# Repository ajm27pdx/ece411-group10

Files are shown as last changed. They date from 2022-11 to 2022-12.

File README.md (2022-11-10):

# ECE411 Group 10 - 2022 Fall Practicum Project

## Members
* Jing Ma
* Adam Martinez
* Janvier Mpfizi
* Tysen Tippetts
## Product Design Specifications
[>>HERE<<](PDS/PDS.md)
## Funcitonal Decomposition
### L0
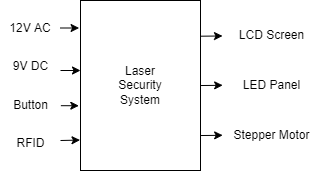
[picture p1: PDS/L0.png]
L0

### L1
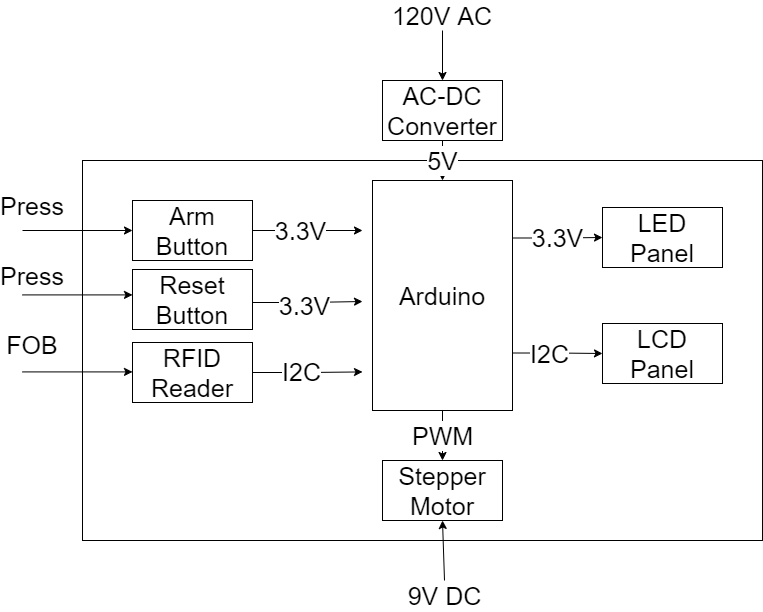
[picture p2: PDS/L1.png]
L1

## Bill of Materials
[Google Sheets Link](https://docs.google.com/spreadsheets/d/1Y6daa6rxvxdisMLShwMxon2ES7SXVknLk-44MzFfnI0/edit?usp=sharing)
### Controllers
- Arduino Uno
### Sensors
- Photoresistors
- RFID Sensor RC522
- Button
### Actuators
- Servo Motor SG90
- LED Lasor 6mm 5mW Red Dot Laser
- LCD Screen 1602 w/ I2C controller
### Misc
- Wires
- RFID Fob
- Resistors
- 3D Printed Enclosure

## Software
- [KiCAD](https://www.kicad.org/) -- Schematic and PCB Layout
- [FreeCAD](https://www.freecadweb.org/) -- 3D Modeling
- [ProjectLibre](https://www.projectlibre.com/) -- Project Management

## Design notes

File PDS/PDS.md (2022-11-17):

# Group 10 - Product Design Specification

## Executive Summary / Concept of Operations
Our product is an anti-theft device that will send out an alert whenever a laser beam across the defensible area is broken. This idea came from spy movies, and we thought that would be useful if we use it to prevent theft from happening. We think most house owners in the world could use it in the room where they keep their valuable things, and some banks, museums, or places that kept confidential information may also be interested in it if the device has enough laser beam to cover the room. Before we are using it, we will need to install the same number of pairs of laser pointers and photoresistors on both sides of the walls, each laser pointer must be precisely aimed at the corresponding photoresistors. There will be a controller that has a series of buttons to arm and reset the device, so it could be turned on and turned off when the buzzer or LED for an alarm on the device is on.
## Brief Market Analysis
Our intended customers are anybody that might have a need to protect a space through the use of a neat, futuristic method. The scale of the product can be altered to protect a hallway or a small enclosure for something important. Our primary competition is other, more mundane security systems such as those that use magnets to secure doors or sonic sensors to secure spaces. As the scale can change based on the needs of the customer, this could lead to a consultation service that can develop and customize the product to each individual’s needs. The components are not particularly expensive, but this service could drive some of the cost.
## Requirements
-   Must have arm/disarm interactions
-   Must detect when the laser beam is broken to the photoresistor
-   Must alert when beam is broken and the alarm is armed, this can be audio and/or visual
-   Must use RFID Fob authorization for disarming
-   Should have a test jig in order to be portable for display
## System Architecture

## Design Specification
### Sensors
- Buttons to arm and disarm, depending on time and desired complexity this can be expanded to a PIN pad or even fingerprint sensor
- Photoresistors to detect the beam and calibrate using ambient light
### Actuators
- An alarm system, can consist of audio buzzers and/or LEDs  
- Servo motor to arm the laser, this is an optional addition
### Processors
- Arduino will be used to the control system
- The Arduino IDE will be able to handle the logic that we’ll need
### Power
- A COTS 5V wall plug will power the Arduino, the stepper motor will have it's own 9V battery power supply through a COTS buck converter.

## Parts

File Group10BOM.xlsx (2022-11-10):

Bill Of Materials for: Team 10 [TEAM NAME]
Last modified: [10/11/2022]
PCB version: [PCB VERSION #]
BOM revision: [BOM REVISION #] |  | P/NP | = Place/Not Place (components marked NP are not stuffed on the board)
Cnt | Part References | P/NP | Mfg | Mfg PN | Description | Dist | Dist Part Number | Cost Ea. | Cost Total
5 | IS1,IS2,IS3, IS4, IS5 | P | IS | 276810 | 1µF ±10% 16V Ceramic Capacitor X5R 0603 | Digi-Key | KY-008 5mW | $0.50 | $2.50
2 | R1,R2 | p | Vishay Dale | CMF5550R000FKEK70 | RES 50 OHM 1/2W 1% AXIAL | Digi-Key | RES 50 OHM 1/2W 1% AXIAL | $0.63 | $1.26
1 | LCD | P | Adafruit Industries LLC | 1528-1505-ND | LCD MODULE 32 DIG 16 X 2 R/G/B | Digikey | 541-4226-ND | $12.00 | $12.00
1 | IDE | p | Arduino | 1050-1024-ND | Arduino Uno R3 | Dig Key | ARDUINO UNO R3 ATMEGA328P EVAL | $27.00 | $27.00
1 | DC Motor | p | Hitec Commercial Solutions | 2589-31311S-ND | HS-311 STANDARD ECONOMY | DigiKey | 31311S | $13.49 | $13.49
1 | Chip | p | NXP USA Inc. | 568-2206-5-ND | IC RFID READER 125KHZ 14SO | GigKey | HTRC11001T/02EE,11 | $4.49 | $4.49
1 | PhotoResistor | p | NTE Electronics, Inc | 2368-02-LDR4-ND | 5MM LDR 30K-50K OHM | DigiKey | 02-LDR4 | $0.23 | $0.23
1 | RfID | NP | MikroElektronika | 1471-1165-ND | RFID READER READ ONLY 125KHZ MOD | DigKey | MIKROE-262 | $24.00 | $24.00
 |  |  |  |  |  |  | TOTAL: | $84.97

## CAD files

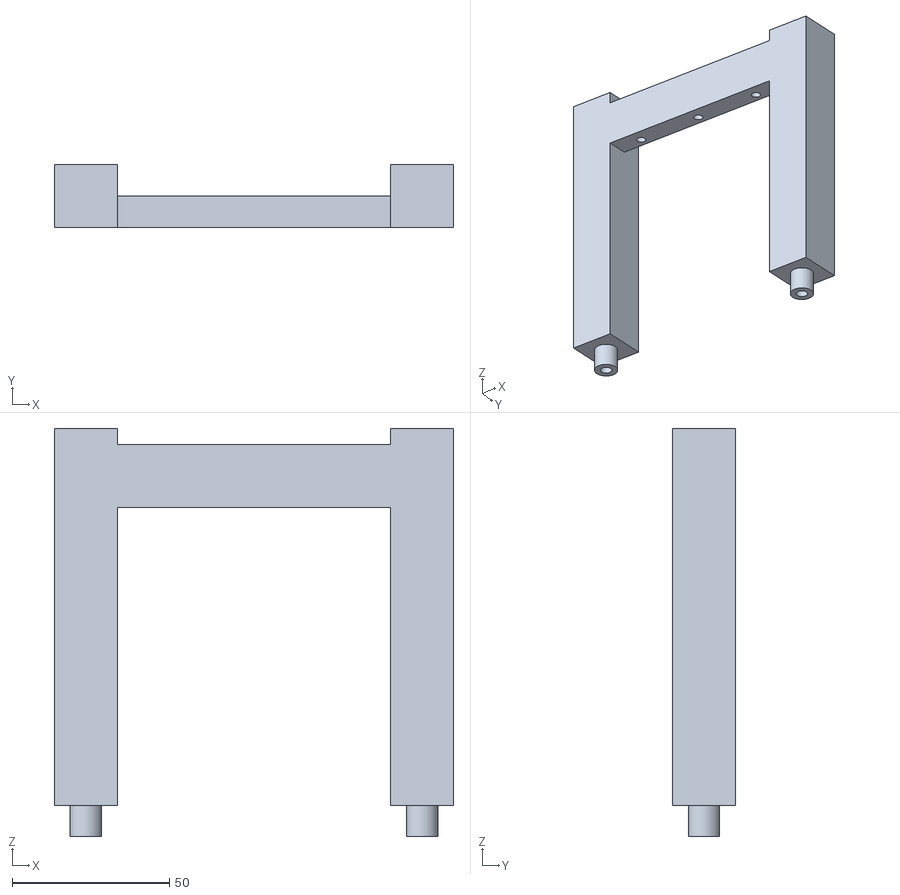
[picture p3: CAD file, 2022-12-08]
CAD/stlFiles/gantryv2.stl
127.0 x 20.0 x 130.0

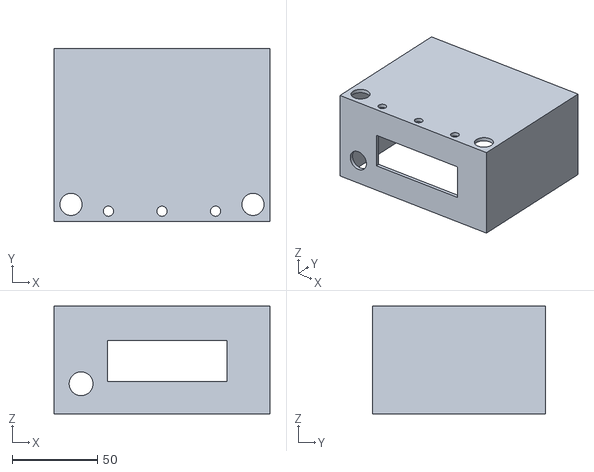
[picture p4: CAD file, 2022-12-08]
CAD/stlFiles/shellv3.stl
127.0 x 101.6 x 63.5

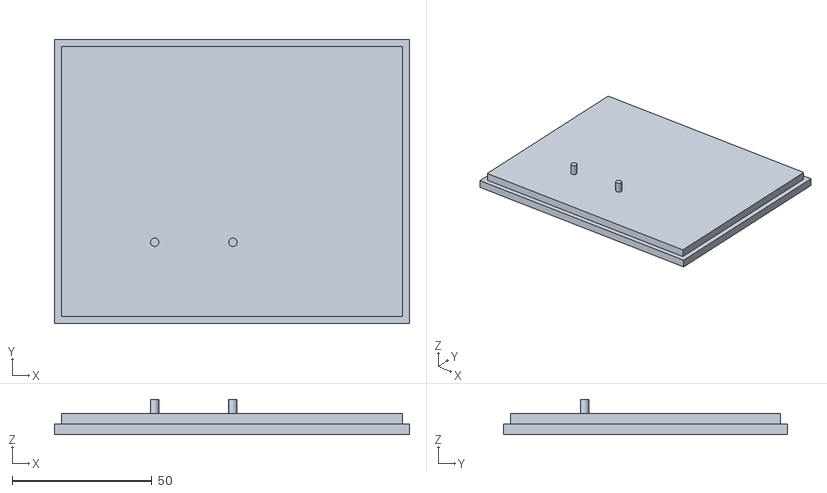
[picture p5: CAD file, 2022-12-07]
CAD/stlFiles/basev1.stl
127.0 x 101.6 x 12.6

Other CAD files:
CAD/stlFiles/shellv2.stl
CAD/stlFiles/gantryv1.stl

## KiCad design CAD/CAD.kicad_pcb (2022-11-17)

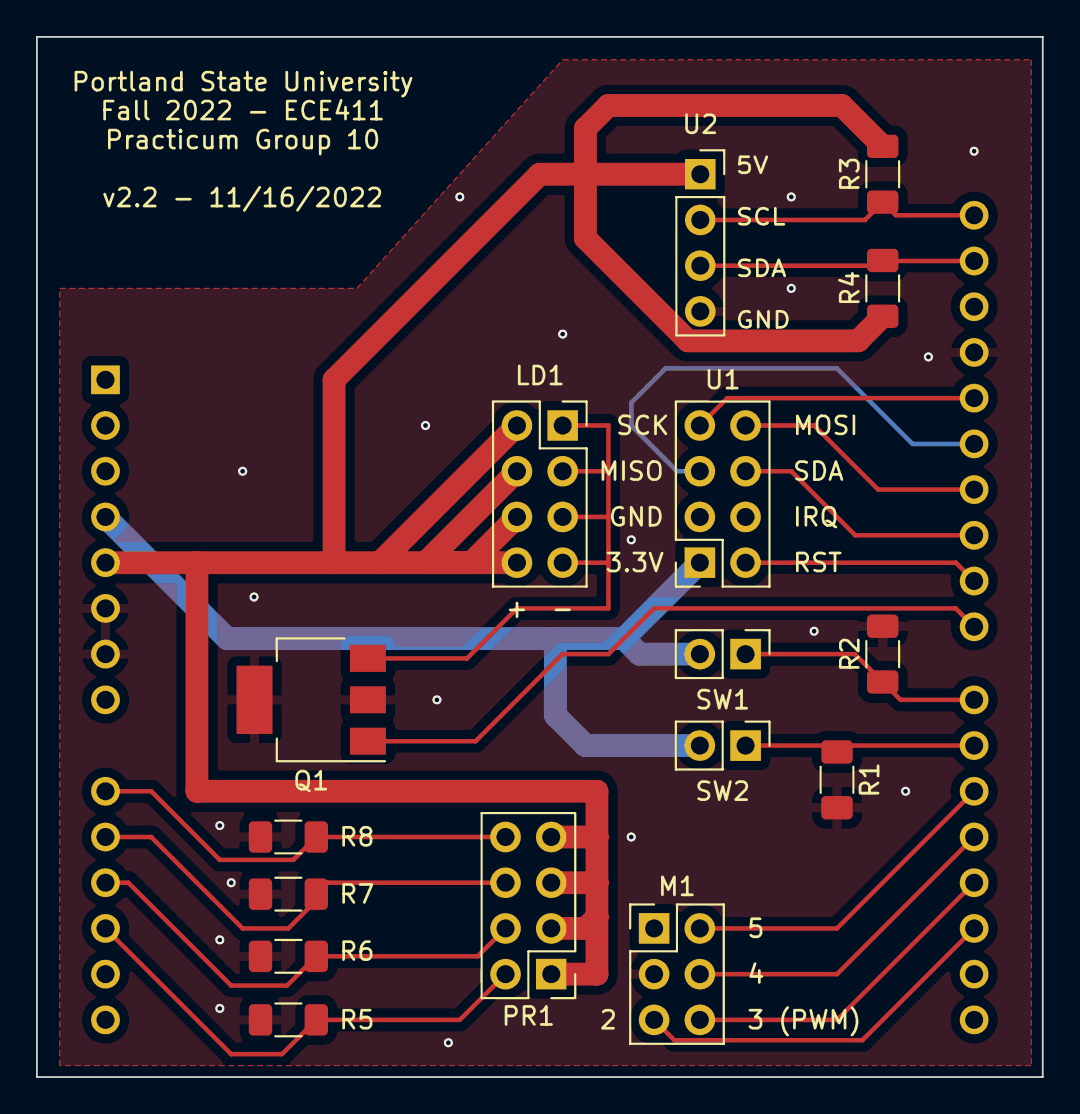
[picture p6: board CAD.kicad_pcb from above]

Board: 2 copper layers, 55.9 x 57.8 mm, 17 parts (1 on the bottom side), 22 nets.

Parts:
A1: Arduino_UNO_R3
LD1: D_Laser_1C2A; PinSocket_2x04_P2.54mm_Vertical
M1: Motor_Servo_Hitec; PinHeader_2x03_P2.54mm_Vertical
PR1: R_Photo; PinHeader_2x04_P2.54mm_Vertical
Q1: 2N7002; SOT-223-3_TabPin2
R1, R2, R5, R6, R7, R8: 10k; R_1206_3216Metric_Pad1.30x1.75mm_HandSolder
R3, R4: 4.7k; R_1206_3216Metric_Pad1.30x1.75mm_HandSolder
SW1, SW2: SW_Push; PinHeader_1x02_P2.54mm_Vertical
U1: RFID_RC522; PinSocket_2x04_P2.54mm_Vertical
U2: LCD_1602_I2C; PinSocket_1x04_P2.54mm_Vertical

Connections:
+3.3V: A1.4 (3V3), SW1.2, SW2.2, U1.1 (3.3V)
+5V: A1.5 (+5V), LD1.2 (A), LD1.4, LD1.6, LD1.8, PR1.1, PR1.3, PR1.5, PR1.7, R3.2, R4.1, U2.1 (VCC)
GND: A1.6 (GND), A1.7 (GND), A1.29 (GND), M1.3 (-), Q1.2 (S), R1.2, R2.2, R5.2, R6.2, R7.2, R8.2, U2.4 (GND)
unnamed: A1.9 (A0), PR1.8, R8.1
unnamed: A1.10 (A1), PR1.6, R7.1
unnamed: A1.11 (A2), PR1.4, R6.1
unnamed: A1.12 (A3), PR1.2, R5.1
unnamed: A1.17 (D2), M1.5
unnamed: A1.18 (D3), M1.6
unnamed: A1.19 (D4), M1.4
unnamed: A1.20 (D5), M1.2 (PWM)
unnamed: A1.21 (D6), R1.1, SW2.1
unnamed: A1.22 (D7), R2.1, SW1.1
unnamed: A1.23 (D8), Q1.1 (G)
unnamed: A1.24 (D9), U1.2 (RST)
unnamed: A1.25 (D10), U1.6 (SDA)
unnamed: A1.26 (D11), U1.8 (MOSI)
unnamed: A1.27 (D12), U1.5 (MISO)
unnamed: A1.28 (D13), U1.7 (SLK)
unnamed: A1.31 (SDA/A4), R4.2, U2.3 (SDA)
unnamed: A1.32 (SCL/A5), R3.1, U2.2 (SCL)
unnamed: LD1.1 (K), LD1.3, LD1.5, LD1.7, Q1.3 (D)

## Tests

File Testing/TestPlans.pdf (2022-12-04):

Test Author: Adam Martinez
Test Case Name: | RFID User Authentication | Test ID #: | 001
Description: | This will test the functionality to disarm the system with an authorized fob to reject an attempt by an unauthorized fob | Type: | □ white box □ black box □ ________

Tester Information
| Name of Tester: | | Date:
| HW/SW Version: | | Time:
| Setup: | System is powered and in the disarmed state, ensure that one fob is authorized and one is not
S T E P | Action | Expected Result | P A S S | F A I L | N / A | Comments
1 | Press ‘Arm’ button | System will enter armed state and confirm on LCD
2 | Pass unauthorized fob near reader | LCD will state the user is unauthorized, system will remain armed
3 | Pass authorized fob near reader | LCD will state that user is authorized, system will enter disarmed state

4
5
6
7
8
9
| Overall test result:

Test Author: Adam Martinez
Test Case Name: | Security Response | Test ID #: | 002
Description: | This will test the system’s response when in the armed state | Type: | □ white box □ black box □ ________

Tester Information
| Name of Tester: | | Date:
| HW/SW Version: | | Time:
| Setup: | System is powered and in the disarmed state
S T E P | Action | Expected Result | P A S S | F A I L | N / A | Comments
1 | Press ‘Arm’ button | System will enter armed state and confirm on LCD
2 | Use hand or object to break photoresistor beam | Shield will release

3
4
5
6
7
8
9
| Overall test result:

Test Author: Adam Martinez
Test Case Name: | Arm - Trigger - Reset Stress Test | Test ID #: | 003
Description: | This test will consist of arming the system, triggering the security response, resetting the system, and repeating this 10x to ensure that it doesn’t get stuck. | Type: | □ white box □ black box □ ________

Tester Information
| Name of Tester: | | Date:
| HW/SW Version: | | Time:
| Setup: | System is powered and in the disarmed state
S T E P | Action | Expected Result | P A S S | F A I L | N / A | Comments
1 | Press ‘Arm’ button | System will enter armed state and confirm on LCD
2 | Use hand or object to break photoresistor beam | Shield will release
3 | Reset Shield
4 | Repeat x10 | System should not lock and retain functionality for each
5
6
7
8
9
| Overall test result:

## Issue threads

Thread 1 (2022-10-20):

Doesn't Work!

ajm27pdx, 2022-10-20:
There's only a design concept here, no code, no schematics, wtf?

Closed 2022-12-08.

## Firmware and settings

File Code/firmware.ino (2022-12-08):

#include <Wire.h>
#include <LiquidCrystal_I2C.h>
#include <SPI.h>
#include <MFRC522.h>
#include <Servo.h>

#define SS_PIN 10
#define RST_PIN 9
MFRC522 mfrc522(SS_PIN, RST_PIN); 

LiquidCrystal_I2C lcd(0x27,20,4);
Servo Myservo;

int laserPin1 = 8;
int buttonPin = 2;
int ledPin = 7;
int ledPin2 = 4;
int buzzer = 5;
int pos = 0;

byte lastbuttonState = LOW;
byte laserPin1State = LOW;
byte ledState = LOW;
byte ledState2 = LOW;

unsigned long debounceDuration = 50;
unsigned long lastTimeButtonStateChanged = 0;


void setup() {
  Serial.begin(9600);
  lcd.begin();
  lcd.clear();
  pinMode(laserPin1, OUTPUT);
  pinMode(buttonPin, INPUT);
  pinMode(ledPin, OUTPUT);
  pinMode(ledPin2, OUTPUT);
  pinMode(buzzer, OUTPUT);
  SPI.begin();      
  mfrc522.PCD_Init();   
  Serial.println("Approximate your card to the reader...");
  Serial.println();
  Myservo.attach(3);

}

void loop() 
{
  digitalWrite(ledPin2, ledState2);

  byte buttonState = digitalRead(buttonPin);
  buttonState = digitalRead(buttonPin);

  if (digitalRead(buttonPin) == LOW) {
    Myservo.write(180);
  }
  else {
    Myservo.write(0);
  }


  while (ledState2 == LOW) {
    while (laserPin1State == LOW) {
      if ( ! mfrc522.PICC_IsNewCardPresent()) 
      {
        return;
      }
  
      if ( ! mfrc522.PICC_ReadCardSerial()) 
      {
        return;
      }
 
      Serial.print("UID tag :");
      String content= "";
      byte letter;
      for (byte i = 0; i < mfrc522.uid.size; i++) 
      {
        Serial.print(mfrc522.uid.uidByte[i] < 0x10 ? " 0" : " ");
        Serial.print(mfrc522.uid.uidByte[i], HEX);
        content.concat(String(mfrc522.uid.uidByte[i] < 0x10 ? " 0" : " "));
        content.concat(String(mfrc522.uid.uidByte[i], HEX));
      }
      Serial.println();
      Serial.print("Message : ");
      content.toUpperCase();
      if (content.substring(1) == "43 4F 9E A9") // Make sure you change this with your own UID number
      {
        Serial.println("Authorised access");
        Serial.println();
        laserPin1State = HIGH;
        digitalWrite(laserPin1, laserPin1State);
        ledState = HIGH;
        digitalWrite(ledPin, ledState);
        delay(100);
      }
 
      else if (content.substring(1) == "DA 81 0F B0")  {
        Serial.println(" Access denied");
        delay(100);
      }
    }

    if (laserPin1State == HIGH ){
      delay(100);
      int value = analogRead(A0);
      int value1 = analogRead(A1);
      int value2 = analogRead(A2);
      if (value < 900 && laserPin1State == HIGH) {
        ledState2 = HIGH;
        digitalWrite(ledPin2, ledState2);
        digitalWrite(buzzer, LOW); //Temp
        lcd.backlight();
        lcd.setCursor(1,0);
        lcd.print("Invade!!");
        lcd.setCursor(1,1);
        lcd.print("Warning!!");
        Myservo.write(180);
      }
      else if (value1 < 900 && laserPin1State == HIGH) {
        ledState2 = HIGH;
        digitalWrite(ledPin2, ledState2);
        digitalWrite(buzzer, LOW); //Temp
        lcd.backlight();
        lcd.setCursor(1,0);
        lcd.print("Invade!!");
        lcd.setCursor(1,1);
        lcd.print("Warning!!");
        Myservo.write(180);
      }
      else if (value2 < 900 && laserPin1State == HIGH) {
        ledState2 = HIGH;
        digitalWrite(ledPin2, ledState2);
        digitalWrite(buzzer, LOW); //Temp
        lcd.backlight();
        lcd.setCursor(1,0);
        lcd.print("Invade!!");
        lcd.setCursor(1,1);
        lcd.print("Warning!!");
        Myservo.write(180);
      }

      if ( ! mfrc522.PICC_IsNewCardPresent()) 
      {
        return;
      }
  
      if ( ! mfrc522.PICC_ReadCardSerial()) 
      {
        return;
      }
 
      Serial.print("UID tag :");
      String content= "";
      byte letter;
      for (byte i = 0; i < mfrc522.uid.size; i++) 
      {
        Serial.print(mfrc522.uid.uidByte[i] < 0x10 ? " 0" : " ");
        Serial.print(mfrc522.uid.uidByte[i], HEX);
        content.concat(String(mfrc522.uid.uidByte[i] < 0x10 ? " 0" : " "));
        content.concat(String(mfrc522.uid.uidByte[i], HEX));
      }
      Serial.println();
      Serial.print("Message : ");
      content.toUpperCase();
      if (content.substring(1) == "43 4F 9E A9") // Make sure you change this with your own UID number
      {
        Serial.println("Authorised access");
        Serial.println();
        laserPin1State = HIGH;
        digitalWrite(laserPin1, laserPin1State);
        ledState = HIGH;
        digitalWrite(ledPin, ledState);
        delay(100);
      }
 
      else if (content.substring(1) == "DA 81 0F B0")  {
        Serial.println(" Access denied");
        laserPin1State = LOW;
        digitalWrite(laserPin1, laserPin1State);
        ledState = LOW;
        digitalWrite(ledPin, ledState);
        ledState2 = LOW;
        digitalWrite(ledPin2, ledState2); 
        digitalWrite(buzzer, ledState2);
        lcd.begin();
        lcd.clear();
        delay(100);
      }
    
    }
  }

  if ( ! mfrc522.PICC_IsNewCardPresent()) 
    {
      return;
    }
  
    if ( ! mfrc522.PICC_ReadCardSerial()) 
    {
      return;
    }
 
    Serial.print("UID tag :");
    String content= "";
    byte letter;
    for (byte i = 0; i < mfrc522.uid.size; i++) 
    {
      Serial.print(mfrc522.uid.uidByte[i] < 0x10 ? " 0" : " ");
      Serial.print(mfrc522.uid.uidByte[i], HEX);
      content.concat(String(mfrc522.uid.uidByte[i] < 0x10 ? " 0" : " "));
      content.concat(String(mfrc522.uid.uidByte[i], HEX));
    }
    Serial.println();
    Serial.print("Message : ");
    content.toUpperCase();
    if (content.substring(1) == "43 4F 9E A9") // Make sure you change this with your own UID number
    {
      Serial.println("Authorised access");
      Serial.println();
      laserPin1State = HIGH;
      digitalWrite(laserPin1, laserPin1State);
      ledState = HIGH;
      digitalWrite(ledPin, ledState);
      delay(3000);
    }
 
    else if (content.substring(1) == "DA 81 0F B0")  {
      Serial.println(" Access denied");
      laserPin1State = LOW;
      digitalWrite(laserPin1, laserPin1State);
      ledState = LOW;
      digitalWrite(ledPin, ledState);
      ledState2 = LOW;
      digitalWrite(ledPin2, ledState2); 
      digitalWrite(buzzer, ledState2);
      lcd.begin();
      lcd.clear();
      delay(3000);
    }

}

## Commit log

2022-11-03 Added prototype demo
2022-11-03 added pcb layout v0.1
    [CAD.kicad_pcb, CAD.kicad_sch]
2022-11-10 updated pcb layout with template
    [CAD.kicad_pcb, CAD.kicad_sch]
2022-11-10 added BOM
    [CAD.kicad_pcb, CAD.kicad_sch, Group10BOM.xlsx]
2022-11-10 Fixed pcb footprints, passing DRC!
    [CAD.kicad_pcb, CAD.kicad_sch]
2022-11-17 Final CAD
    [CAD.kicad_pcb, CAD.kicad_sch]
2022-12-07 added stl files
    [basev1.stl, gantryv1.stl, shellv2.stl]
2022-12-08 final version of stl files
    [gantryv2.stl, shellv3.stl]
